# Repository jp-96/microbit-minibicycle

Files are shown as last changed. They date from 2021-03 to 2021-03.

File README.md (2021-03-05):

# はじめに

在宅勤務が増え、外出する頻度も少なくなり、運動不足が続いていませんか。BBC micro:bitを活用したプログラミングをしてみましょう。  

[micro:bit mini bicycle](https://github.com/jp-96/microbit-minibicycle)をmicro:bitにインストールすると、マグネット負荷方式の家庭向けサイクルトレーナーの負荷を制御したり、クランクのセンサーから回転数や速度、パワーを算出したりすることが可能となります。また、micro:bitのBluetooth機能を使って、スマホなどと無線通信でき、スマホから、負荷の強度を変更できたり、スマホで回転数や速度、パワーを確認したりできます。

> 補足：BBC micro:bit v1.5をターゲットとしています。  

## 例：マグネット負荷方式の家庭向けサイクルトレーナー

[Amazon: マグネティックバイクミニ （黄色）- 10588](https://amzn.to/3bm5ly5)  
[Amazon: マグネティックバイクミニ （白色）-  9593](https://amzn.to/3bqcnBW)  

# インストール方法

<div style="text-align: center">
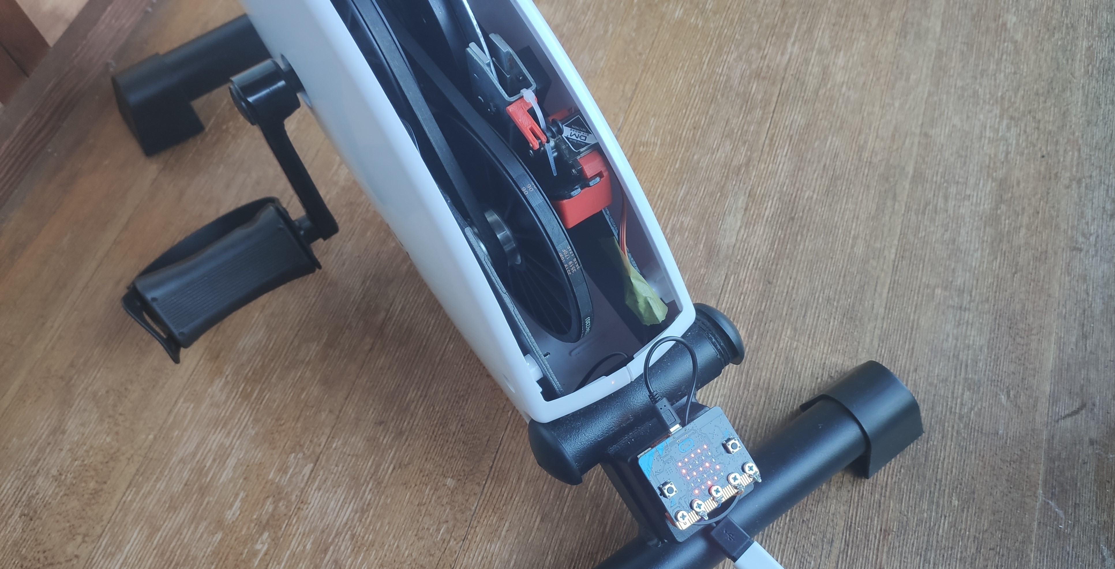
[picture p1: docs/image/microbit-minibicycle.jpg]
micro:bit mini bicycle

</div>

## 必要なもの

1. micro:bit本体 (v1.5)
1. 小型サーボモーター(MG90S等)
1. マグネット負荷方式の家庭向けサイクルトレーナー
1. 3Dプリンターで作成した[パーツ(/docs/print3d/)](/docs/print3d/)
1. 工具、ネジ、配線部品等
1. コンパイル済みのHEX形式ファイル

## コンパイル済みのHEX形式ファイル

次のいずれかの方法で、HEXファイルを入手し、micro:bitに転送（コピー）します。

1. githubからコンパイル済みのHEXファイルをダウンロードする
1. mbed オンライン コンパイラで、プログラムをインポートし、コンパイルする

### 入手方法1 - githubからコンパイル済みのHEXファイルをダウンロードする

次のリンクからHEX形式ファイルをダウンロードし、micro:bitへ転送（コピー）します。  
[microbit-minibicycle.hex](docs/build/microbit-minibicycle.hex)

### 入手方法2 - mbed オンライン コンパイラで、プログラムをインポートし、コンパイルする

1. Mbed オンライン コンパイラを開きます  
   https://ide.mbed.com/compiler/
1. プログラムをインポートします  
   https://github.com/jp-96/microbit-minibicycle.git
1. コンパイルを実行し、コンパイルに成功すると、HEX形式ファイルがダウンロードされます
1. ダウンロードしたHEX形式ファイルをmicro:bitへ転送（コピー）します

## 接続方法

小型サーボモーターをmicro:bitのP1端子へ、センサー信号をmicro:bitのP2端子へそれぞれ接続します。  
配線方法については、手書きの回路図を参考にしてください。

<div style="text-align: center">
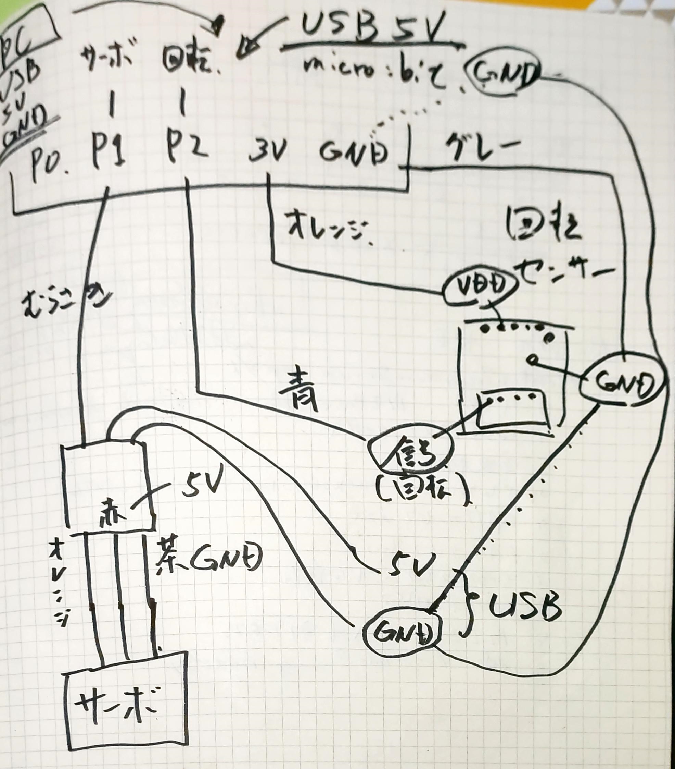
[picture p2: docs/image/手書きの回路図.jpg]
手書きの回路図

</div>

# 使い方

micro:bitのAボタンとBボタンで、負荷を1から8まで変更できます。  
スマホの汎用BLEアプリで、`BIKEMINI:BIT`に接続すると、回転数や速度、パワーを確認したり、スマホから、負荷の強度を変更できたりします。

**【汎用BLEアプリ】**

[Google Play - nRF Connect for Mobile](https://play.google.com/store/apps/details?id=no.nordicsemi.android.mcp&hl=ja&gl=US)  
[App Store - nRF Connect: Bluetooth App](https://apps.apple.com/jp/app/nrf-connect/id1054362403)

## バーチャルライド

いくつかのバーチャルライドアプリも対応していますので、試してみてください。

1. Zwift - https://www.zwift.com/
1. Kinomap - https://www.kinomap.com/
1. RGT CYCLING - https://www.rgtcycling.com/
1. OneLap - https://www.onelapjapan.jp/ , https://www.onelap.com/

# 開発

## モジュールの構成 - シーケンス図

開発当初のシーケンス図をメモとして残しておきます。実装とは異なっています。

<div style="text-align: center">
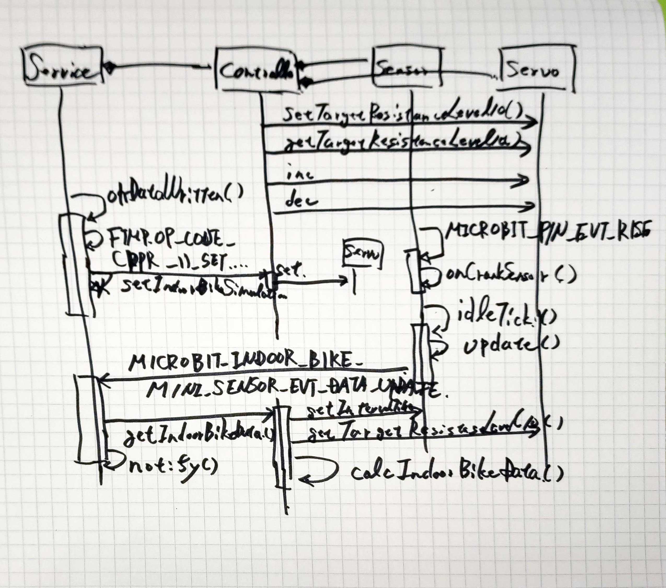
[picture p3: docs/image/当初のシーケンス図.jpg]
当初のシーケンス図

</div>

# 【おまけ】 Windows10でコンパイルする方法

## ツールのインストール 

1. [Git](https://git-scm.com/)
2. [Mercurial](https://www.mercurial-scm.org/)
3. [GNU Arm Embedded Toolchain](https://developer.arm.com/tools-and-software/open-source-software/developer-tools/gnu-toolchain/gnu-rm/downloads) - [**6-2017-q2-update**](https://developer.arm.com/-/media/Files/downloads/gnu-rm/6-2017q2/gcc-arm-none-eabi-6-2017-q2-update-win32-sha2.exe)  
※ GNU Arm Embedded Toolchain  
  → [gcc-arm-none-eabi-6-2017-q2-update-win32-sha2.exe](https://developer.arm.com/-/media/Files/downloads/gnu-rm/6-2017q2/gcc-arm-none-eabi-6-2017-q2-update-win32-sha2.exe)
4. [Python3](https://www.python.org/downloads/)

## 環境構築

コマンドプロンプトを開き、次のコマンドを実行します。  

```CommandPrompt.cmd
py -3 -m pip install --upgrade virtualenv
mkdir c:\workubit
cd c:\workubit
py -3 -m virtualenv venv
C:\workubit\venv\Scripts\activate.bat
pip install mbed-cli git+https://github.com/jp-rad/mbed-microbit-win10-setup.git
mbed config --global GCC_ARM_PATH "C:\Program Files (x86)\GNU Tools Arm Embedded\6 2017-q2-update\bin"

```

## git clone

コマンドプロンプトを開き、次のコマンドを実行します。  

```CommandPrompt.cmd
C:\workubit\venv\Scripts\activate.bat
cd c:\workubit
git clone https://github.com/jp-96/microbit-minibicycle
```

## ライブラリのインポート

コマンドプロンプトを開き、次のコマンドを実行します。     

```CommandPrompt.cmd
C:\workubit\venv\Scripts\activate.bat
cd c:\workubit\microbit-minibicycle
mbedubitwin10

```

## コンパイル

パソコンにBBC micro:bitを接続し、例えば、Dドライブとして認識させます。   
コマンドプロンプトを開き、次のコマンドを実行します。     

```CommandPrompt.cmd
C:\workubit\venv\Scripts\activate.bat
cd c:\workubit\microbit-minibicycle

mbed compile
copy /Y .\BUILD\NRF51_MICROBIT\GCC_ARM\microbit-minibicycle.hex  .\docs\build
copy .\BUILD\NRF51_MICROBIT\GCC_ARM\microbit-minibicycle.hex d:\
```

# リンク

## Pythonパッケージ

[mbedubitwin10](https://github.com/jp-rad/mbed-microbit-win10-setup.git)

## GitHubテンプレート

[mbed-microbit-template](https://github.com/jp-rad/mbed-microbit-template.git)

## micro:bit runtime

[micro:bit runtime docs](https://lancaster-university.github.io/microbit-docs/)

## BBC Community Guidelines

[Microbit Community Guidelines](http://microbit.org/community/)

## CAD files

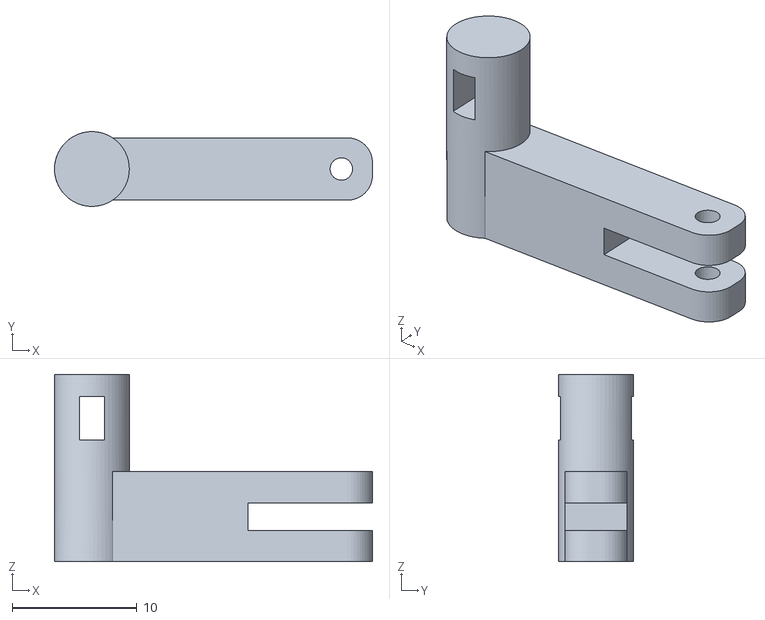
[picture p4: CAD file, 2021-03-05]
docs/print3d/simple-arm-mini.stl
25.5 x 6.00 x 15.0

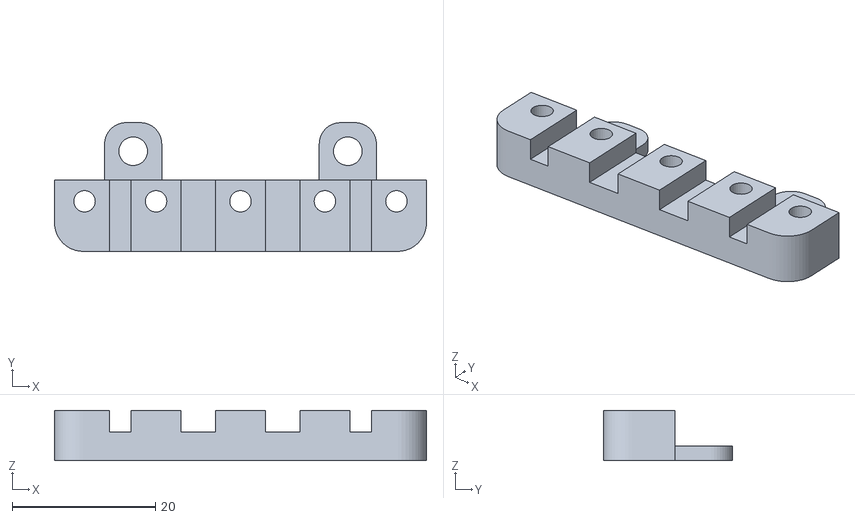
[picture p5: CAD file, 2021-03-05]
docs/print3d/minibike-microbit.stl
52.0 x 18.0 x 7.00

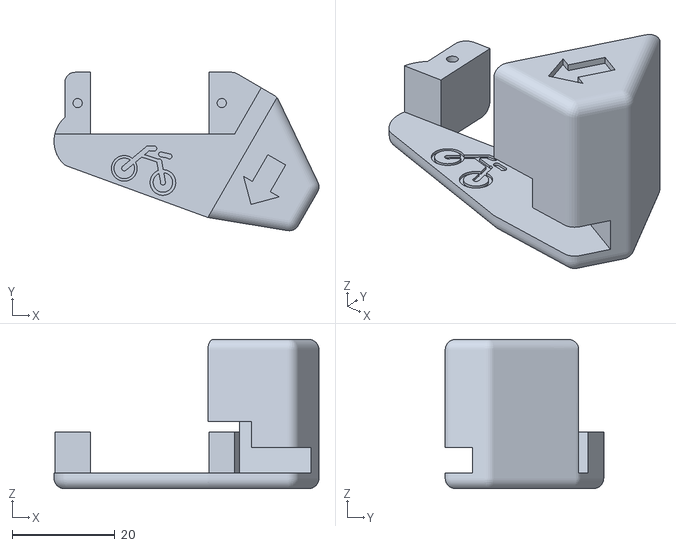
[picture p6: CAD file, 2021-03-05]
docs/print3d/servo-handmini.stl
51.5 x 30.8 x 29.0

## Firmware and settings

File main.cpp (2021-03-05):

/*
MIT License

Copyright (c) 2021 jp-rad

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
*/

#include "inttypes.h"
#include "MicroBit.h"
#include "MicroBitCustom.h"
#include "MicroBitIndoorBikeMiniSensor.h"
#include "MicroBitIndoorBikeMiniServo.h"
#include "MicroBitIndoorBikeMiniController.h"
#include "MicroBitIndoorBikeMiniService.h"

#ifndef BLE_DEVICE_LOCAL_NAME_CHENGE
#define BLE_DEVICE_LOCAL_NAME_CHENGE 0
#endif /* #ifndef BLE_DEVICE_LOCAL_NAME_CHENGE */

MicroBit uBit;

MicroBitIndoorBikeMiniSensor* sensor;
MicroBitIndoorBikeMiniServo* servo;
MicroBitIndoorBikeMiniController* controller;
MicroBitIndoorBikeMiniService* service;

// Recalc indoor bike data.
void calcIndoorBikeData(MicroBitIndoorBikeMiniController* sender, uint8_t resistanceLevel10, uint32_t crankIntervalTime, uint32_t* cadence2, uint32_t* speed100, int32_t*  power)
{
    *power = *power * 1.2;
}

// Button Event
void onButton(MicroBitEvent e)
{
    switch (e.source)
    {
    case MICROBIT_ID_BUTTON_A:
        controller->decrementTargetResistanceLevel10();
        break;
    
    case MICROBIT_ID_BUTTON_B:
        controller->incrementTargetResistanceLevel10();
        break;
    
    default:
        break;
    }
}

void setup()
{
    // BLE Appearance and LOCAL_NAME
    uBit.ble->gap().accumulateAdvertisingPayload(GapAdvertisingData::GENERIC_CYCLING);
    if (BLE_DEVICE_LOCAL_NAME_CHENGE)
    {
        uBit.ble->gap().accumulateAdvertisingPayload(GapAdvertisingData::COMPLETE_LOCAL_NAME
            , (const uint8_t *)BLE_DEVICE_LOCAL_NAME, sizeof(BLE_DEVICE_LOCAL_NAME)-1);
    }

    // Register for Button Events on Button(A)
    uBit.messageBus.listen(MICROBIT_ID_BUTTON_A, MICROBIT_BUTTON_EVT_CLICK, onButton);
    uBit.messageBus.listen(MICROBIT_ID_BUTTON_B, MICROBIT_BUTTON_EVT_CLICK, onButton);
    
    // driver
    sensor = new MicroBitIndoorBikeMiniSensor(uBit);
    servo = new MicroBitIndoorBikeMiniServo(uBit);
    //servo->idleTick();
    controller = new MicroBitIndoorBikeMiniController(uBit, *sensor, *servo, calcIndoorBikeData);
    controller->idleTick();
    
    // MicroBitIndoorBikeMiniService
    service = new MicroBitIndoorBikeMiniService(*(uBit.ble), *controller);

}

void displayTargetResistanceLevel()
{
    while (true)
    {
        uBit.display.print(ManagedString((int)controller->getTargetResistanceLevel10()/10));
        uBit.sleep(100);
    }
    
}

int main()
{
    uBit.init();
    create_fiber(setup);
    create_fiber(displayTargetResistanceLevel);
    release_fiber();
}

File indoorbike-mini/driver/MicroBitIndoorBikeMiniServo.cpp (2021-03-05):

/*
MIT License

Copyright (c) 2021 jp-rad

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
THE SOFTWARE IS PROVIDED "AS IS", WITHOUT WARRANTY OF ANY KIND, EXPRESS OR
IMPLIED, INCLUDING BUT NOT LIMITED TO THE WARRANTIES OF MERCHANTABILITY,
FITNESS FOR A PARTICULAR PURPOSE AND NONINFRINGEMENT. IN NO EVENT SHALL THE
AUTHORS OR COPYRIGHT HOLDERS BE LIABLE FOR ANY CLAIM, DAMAGES OR OTHER
LIABILITY, WHETHER IN AN ACTION OF CONTRACT, TORT OR OTHERWISE, ARISING FROM,
OUT OF OR IN CONNECTION WITH THE SOFTWARE OR THE USE OR OTHER DEALINGS IN THE
SOFTWARE.
*/

#include "MicroBitIndoorBikeMiniServo.h"

// Constructor.
MicroBitIndoorBikeMiniServo::MicroBitIndoorBikeMiniServo(MicroBit &_uBit, FuncCalcAngle _pFuncCalcAngle, MicrobitIndoorBikeMiniServoPin pin)
    : uBit(_uBit), pFuncCalcAngle(_pFuncCalcAngle)
{
    this->servoPin = NULL;
    switch (pin)
    {
    case SERVO_P0:
        this->servoPin = &(uBit.io.P0);
        break;
    
    case SERVO_P1:
        this->servoPin = &(uBit.io.P1);
        break;
    
    default:
        this->servoPin = &(uBit.io.P2);
        break;
    }
    this->nextServoControlTimestamp = 0;
    this->servoState = SERVO_NONE;
    this->targetResistanceLevel10 = 0;
    this->servoAngle = MICROBIT_INDOOR_BIKE_MINI_SERVO_ANGLE_10;
    this->setTargetResistanceLevel10(VAL_MINIMUM_RESISTANCE_LEVEL);
}

/**
     * Periodic callback from MicroBit idle thread.
     */
void MicroBitIndoorBikeMiniServo::idleTick()
{
    this->update();
}

void MicroBitIndoorBikeMiniServo::update(bool force)
{
    uint64_t currentTime = system_timer_current_time_us();
    if(!(status & MICROBIT_INDOOR_BIKE_MINI_SERVO_ADDED_TO_IDLE))
    {
        // If we're running under a fiber scheduer, register ourselves for a periodic callback to keep our data up to date.
        // Otherwise, we do just do this on demand, when polled through our read() interface.
        fiber_add_idle_component(this);
        status |= MICROBIT_INDOOR_BIKE_MINI_SERVO_ADDED_TO_IDLE;
    }
    
    if (force || this->servoState==SERVO_NONE)
    {
        this->servoState = SERVO_OFF;
        this->nextServoControlTimestamp=currentTime;
    }
    
    if (currentTime >= this->nextServoControlTimestamp)
    {
        switch (this->servoState)
        {
        case SERVO_ON:
            this->servoState = SERVO_OFF;
            // Schedule our next control.
            this->nextServoControlTimestamp = currentTime + this->SERVO_PERIOD_OFF;
            //servoPin->getDigitalValue(PullDown);
            break;

        default:
            this->servoState = SERVO_ON;
            // Schedule our next control.
            this->nextServoControlTimestamp = currentTime + this->SERVO_PERIOD_ON;
            servoPin->setServoValue(this->servoAngle);
            break;
            
        }
    }
}

void MicroBitIndoorBikeMiniServo::setTargetResistanceLevel10(uint8_t targetResistanceLevel10)
{
    if (targetResistanceLevel10 >= VAL_MINIMUM_RESISTANCE_LEVEL
        && targetResistanceLevel10 <= VAL_MAXIMUM_RESISTANCE_LEVEL)
    {
        int angle;
        this->targetResistanceLevel10=targetResistanceLevel10;
        if (this->pFuncCalcAngle)
        {
            angle = (*this->pFuncCalcAngle)(this->targetResistanceLevel10);
        }
        else
        {
            if (this->targetResistanceLevel10<=10)      //10  40
            {
                angle = MICROBIT_INDOOR_BIKE_MINI_SERVO_ANGLE_10;
            }
            else if(this->targetResistanceLevel10<=20)  //20  60
            {
                angle = MICROBIT_INDOOR_BIKE_MINI_SERVO_ANGLE_20;
            }
            else if(this->targetResistanceLevel10<=30)  //30  70
            {
                angle = MICROBIT_INDOOR_BIKE_MINI_SERVO_ANGLE_30;
            }
            else if(this->targetResistanceLevel10<=40)  //40  80
            {
                angle = MICROBIT_INDOOR_BIKE_MINI_SERVO_ANGLE_40;
            }
            else if(this->targetResistanceLevel10<=50)  //50  85
            {
                angle = MICROBIT_INDOOR_BIKE_MINI_SERVO_ANGLE_50;
            }
            else if(this->targetResistanceLevel10<=60)  //60  90
            {
                angle = MICROBIT_INDOOR_BIKE_MINI_SERVO_ANGLE_60;
            }
            else if(this->targetResistanceLevel10<=70)  //70  95
            {
                angle = MICROBIT_INDOOR_BIKE_MINI_SERVO_ANGLE_70;
            }
            else                                        //80 100
            {
                angle = MICROBIT_INDOOR_BIKE_MINI_SERVO_ANGLE_80;
            }
        }
        this->servoAngle = angle;
        this->update(true);
    }
}

uint8_t MicroBitIndoorBikeMiniServo::getTargetResistanceLevel10(void)
{
    return this->targetResistanceLevel10;
}

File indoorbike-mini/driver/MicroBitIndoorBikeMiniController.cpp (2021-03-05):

/*
MIT License

Copyright (c) 2021 jp-rad

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
THE SOFTWARE IS PROVIDED "AS IS", WITHOUT WARRANTY OF ANY KIND, EXPRESS OR
IMPLIED, INCLUDING BUT NOT LIMITED TO THE WARRANTIES OF MERCHANTABILITY,
FITNESS FOR A PARTICULAR PURPOSE AND NONINFRINGEMENT. IN NO EVENT SHALL THE
AUTHORS OR COPYRIGHT HOLDERS BE LIABLE FOR ANY CLAIM, DAMAGES OR OTHER
LIABILITY, WHETHER IN AN ACTION OF CONTRACT, TORT OR OTHERWISE, ARISING FROM,
OUT OF OR IN CONNECTION WITH THE SOFTWARE OR THE USE OR OTHER DEALINGS IN THE
SOFTWARE.
*/

#include "MicroBitIndoorBikeMiniController.h"

void defaultCalcIndoorBikeData(MicroBitIndoorBikeMiniController* sender, uint8_t resistanceLevel10, uint32_t crankIntervalTime, uint32_t* cadence2, uint32_t* speed100, int32_t*  power)
{
    
    if (crankIntervalTime==0)
    {
        *cadence2 = 0;
        *speed100 = 0;
        *power = 0;
    }
    else
    {
        *cadence2  = (uint32_t)( MicroBitIndoorBikeMiniController::K_CRANK_CADENCE / crankIntervalTime );
        *speed100 = (uint32_t)( MicroBitIndoorBikeMiniController::K_CRANK_SPEED   / crankIntervalTime );
        // https://diary.cyclekikou.net/archives/15876
        *power = (int32_t)( (double)(*speed100) * (MicroBitIndoorBikeMiniController::K_INCLINE_A * ((double)resistanceLevel10)/10 + MicroBitIndoorBikeMiniController::K_INCLINE_B) * MicroBitIndoorBikeMiniController::K_POWER);
    }
}

uint8_t defaultCalcTargetResistanceLevel10(MicroBitIndoorBikeMiniController* sender, int16_t windSpeed1000, int16_t grade100, uint8_t crr10000, uint8_t cw100)
{
    uint8_t resistanceLevel10;
    if (grade100<-100)
    {
        resistanceLevel10 = 10;
    }
    else if (grade100<100)
    {
        resistanceLevel10 = 20;
    }
    else if (grade100<300)
    {
        resistanceLevel10 = 30;
    }
    else if (grade100<500)
    {
        resistanceLevel10 = 40;
    }
    else if (grade100<700)
    {
        resistanceLevel10 = 50;
    }
    else if (grade100<900)
    {
        resistanceLevel10 = 60;
    }
    else if (grade100<1100)
    {
        resistanceLevel10 = 70;
    }
    else
    {
        resistanceLevel10 = 80;
    }
    return resistanceLevel10;
}


MicroBitIndoorBikeMiniController::MicroBitIndoorBikeMiniController(MicroBit &_uBit, MicroBitIndoorBikeMiniSensor &_sensor, MicroBitIndoorBikeMiniServo &_servo, FuncCalcIndoorBikeData _pFuncCalcIndoorBikeData, FuncCalcTargetResistanceLevel10 _pFuncCalcTargetResistanceLevel10, uint16_t id)
    : uBit(_uBit), sensor(_sensor), servo(_servo), pFuncCalcIndoorBikeData(_pFuncCalcIndoorBikeData), pFuncCalcTargetResistanceLevel10(_pFuncCalcTargetResistanceLevel10)
{
    this->id = id;
    this->lastCadence2=0;
    this->lastSpeed100=0;
    this->lastPower=0;
    this->updateSampleTimestamp=0;
    this->servo.setTargetResistanceLevel10(VAL_MINIMUM_RESISTANCE_LEVEL);
}

void MicroBitIndoorBikeMiniController::idleTick()
{
    this->update();
}

void MicroBitIndoorBikeMiniController::update(void)
{
    uint64_t currentTime = system_timer_current_time_us();
    if(!(status & MICROBIT_INDOOR_BIKE_MINI_CONTROLLER_ADDED_TO_IDLE))
    {
        // If we're running under a fiber scheduer, register ourselves for a periodic callback to keep our data up to date.
        // Otherwise, we do just do this on demand, when polled through our read() interface.
        fiber_add_idle_component(this);
        status |= MICROBIT_INDOOR_BIKE_MINI_CONTROLLER_ADDED_TO_IDLE;
    }
    
    if (currentTime >= this->updateSampleTimestamp)
    {        
        // Schedule our next sample.
        this->updateSampleTimestamp = currentTime + this->SENSOR_UPDATE_PERIOD_US;
        
        uint8_t resistanceLevel10 = this->servo.getTargetResistanceLevel10();
        uint32_t crankIntervalTime = this->sensor.getCrankIntervalTime();
        defaultCalcIndoorBikeData(this, resistanceLevel10, crankIntervalTime, &this->lastCadence2, &this->lastSpeed100, &this->lastPower);
        if (this->pFuncCalcIndoorBikeData)
        {
            (*this->pFuncCalcIndoorBikeData)(this, resistanceLevel10, crankIntervalTime, &this->lastCadence2, &this->lastSpeed100, &this->lastPower);
        }
        // Send an event to indicate that we'e updated our sensor.
        MicroBitEvent e(id, MICROBIT_INDOOR_BIKE_MINI_CONTROLLER_EVT_DATA_UPDATE);
    }
}

uint32_t MicroBitIndoorBikeMiniController::getCadence2(void)
{
    return this->lastCadence2;
}

uint32_t MicroBitIndoorBikeMiniController::getSpeed100(void)
{
    return this->lastSpeed100;
}

int32_t  MicroBitIndoorBikeMiniController::getPower(void)
{
    return this->lastPower;
}

void MicroBitIndoorBikeMiniController::setTargetResistanceLevel10(uint8_t targetResistanceLevel10)
{
    this->servo.setTargetResistanceLevel10(targetResistanceLevel10);
}

uint8_t MicroBitIndoorBikeMiniController::getTargetResistanceLevel10(void)
{
    return this->servo.getTargetResistanceLevel10();
}

bool MicroBitIndoorBikeMiniController::incrementTargetResistanceLevel10(void)
{
    uint8_t org = this->getTargetResistanceLevel10();
    this->setTargetResistanceLevel10(this->getTargetResistanceLevel10() + VAL_INCREMENT_RESISTANCE_LEVEL);
    return org!=this->getTargetResistanceLevel10();
}

bool MicroBitIndoorBikeMiniController::decrementTargetResistanceLevel10(void)
{
    uint8_t org = this->getTargetResistanceLevel10();
    this->setTargetResistanceLevel10(this->getTargetResistanceLevel10() - VAL_INCREMENT_RESISTANCE_LEVEL);
    return org!=this->getTargetResistanceLevel10();
}

void MicroBitIndoorBikeMiniController::setIndoorBikeSimulation(int16_t windSpeed1000, int16_t grade100, uint8_t crr10000, uint8_t cw100)
{   
    FuncCalcTargetResistanceLevel10 pFunc;
    if (this->pFuncCalcTargetResistanceLevel10)
    {
        pFunc = this->pFuncCalcTargetResistanceLevel10;
    }
    else
    {
        pFunc = defaultCalcTargetResistanceLevel10;
    }
    this->setTargetResistanceLevel10(pFunc(this, windSpeed1000, grade100, crr10000, cw100));
}

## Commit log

2021-01-01 SpeedSensorの追加
2021-01-01 センサーイベントと係数調整済み
2021-01-01 CadenceSensorへ名称変更
2021-01-02 driver化
2021-01-02 pinのイベントは外部から
2021-01-03 PIN制御の隠蔽化
2021-01-03 PIN指定可能
2021-01-03 メンバー関数のLissten化とBLEの有効化
2021-01-03 カスタムイベントIDのconst化
2021-01-03 BLE実装
2021-01-04 キャラクタスティックの定義
2021-01-05 未実装 - FTMP_OP_CODE_CPPR_11_SET_INDOOR_BIKE_SIMULATION
2021-01-06 FTMSの実装
2021-01-09 printf, servo
2021-01-10 parts STL
    [minibike-microbit.stl, servo-handmini.stl, simple-arm-mini.stl]
2021-01-11 3Dデータへの参照
2021-03-04 イベントの見直し、関数化と外だし
2021-03-04 WatchdogTimer.libの廃止
